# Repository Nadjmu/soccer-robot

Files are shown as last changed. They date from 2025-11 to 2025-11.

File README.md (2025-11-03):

# soccer-robot
This repository contains the schematic, the board design, the mechanical design (3D CAD Models) and the code for our autonomous soccer robot when we participated in the Soccer Lightweight League at the RoboCup Junior 2019. 

The rules can be found on the following website: https://junior.robocup.org/soccer/

The design of the motherboard and the ground board was done with Autodesk Eagle. The design of the mechanical components was done with the CAD Software Autodesk Inventor. The software was written with Arduino. 

This is a video where we played against Russia in the European Championship: https://www.youtube.com/watch?v=PZbQC_VygyU

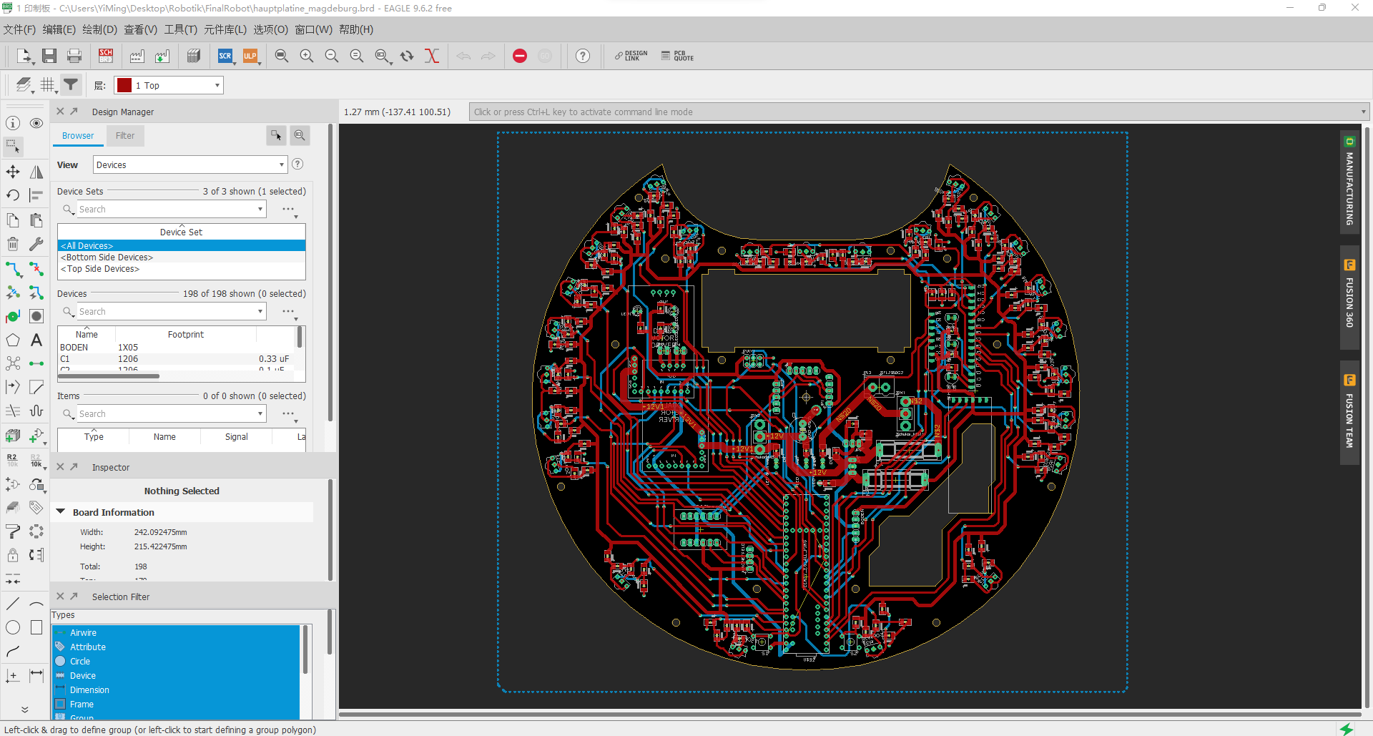
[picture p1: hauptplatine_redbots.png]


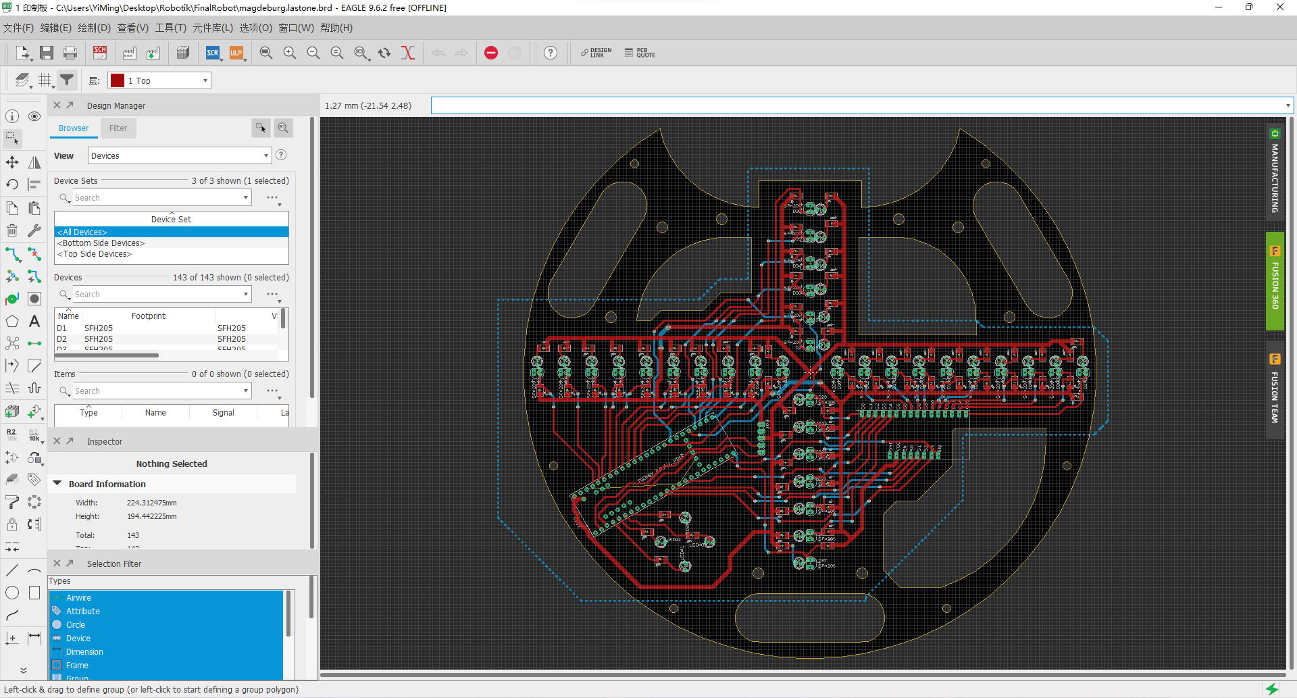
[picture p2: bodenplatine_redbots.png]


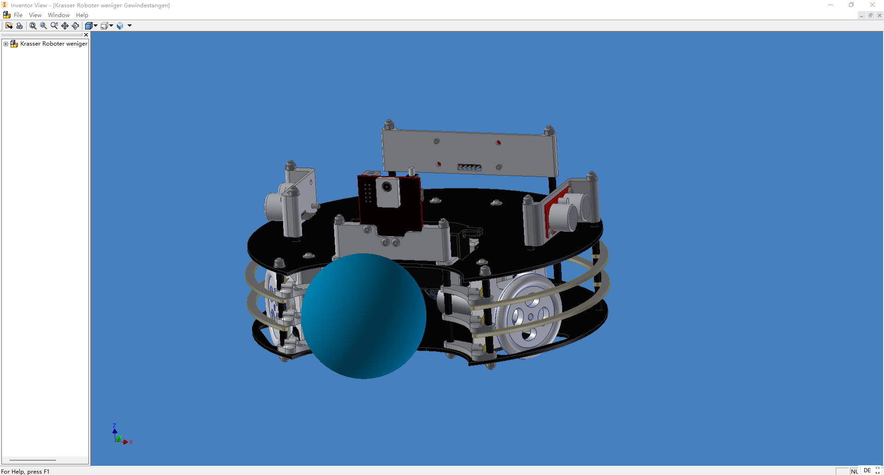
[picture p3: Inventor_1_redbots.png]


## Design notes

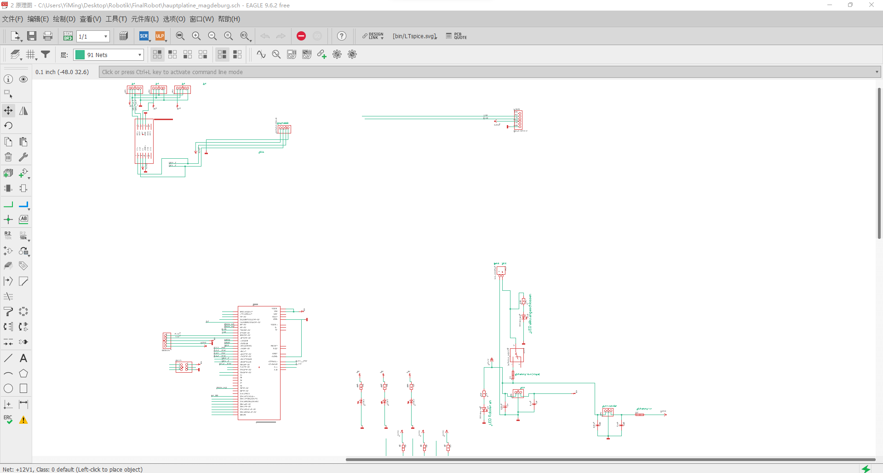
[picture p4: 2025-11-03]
schaltplan_redbots.png

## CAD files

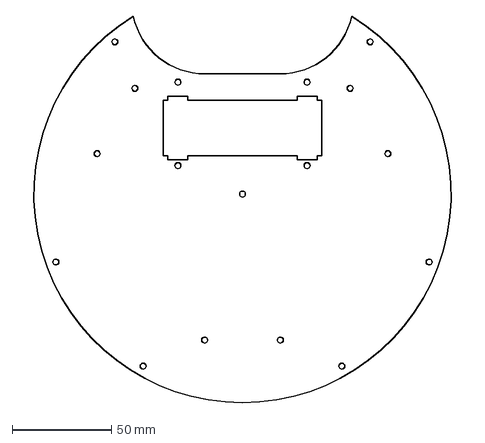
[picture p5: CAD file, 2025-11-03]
CAD_files/Hauptplatine.dxf
227.6 x 194.4 mm

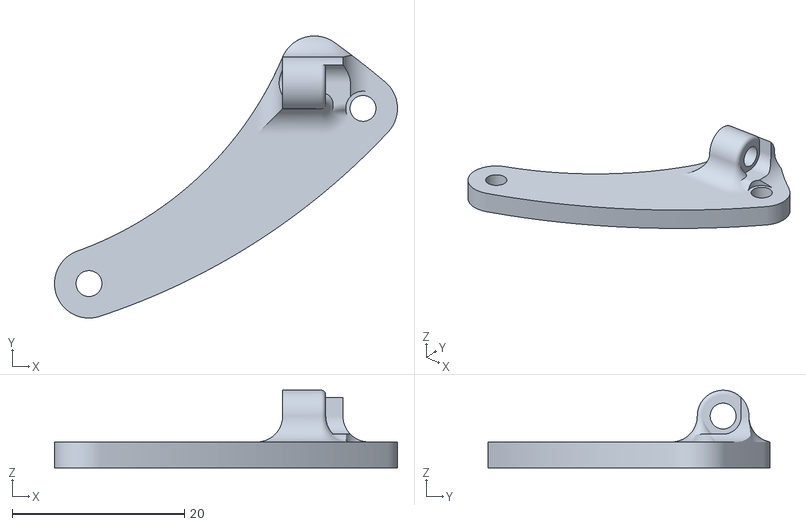
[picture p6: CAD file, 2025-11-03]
CAD_files/STL/Halterung Lichtschranke links.stl
39.8 x 32.7 x 9.00

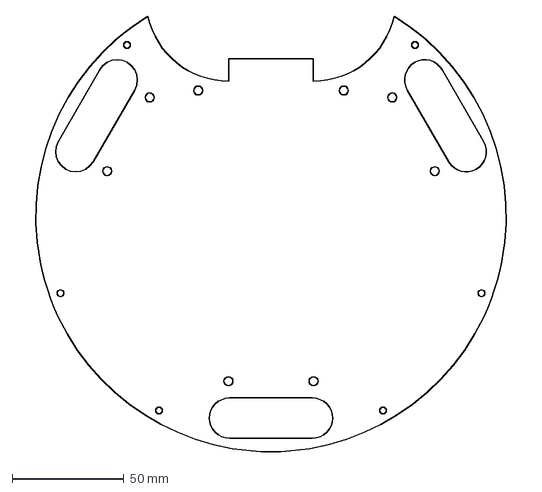
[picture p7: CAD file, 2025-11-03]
CAD_files/umriss.dxf
227.6 x 194.4 mm

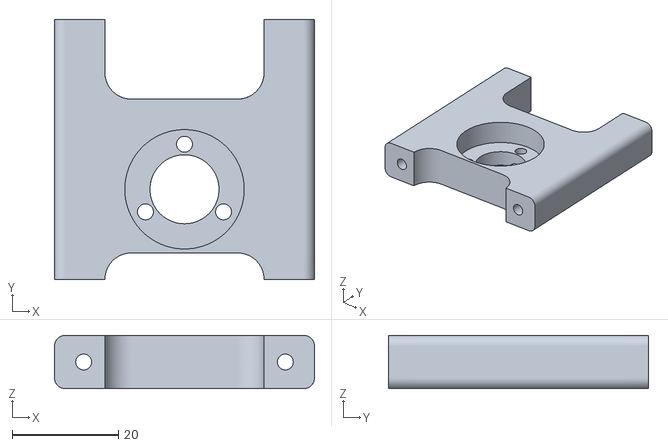
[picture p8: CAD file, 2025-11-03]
CAD_files/STL/Motorhalterung leicht versuch dünn.stl
49.0 x 49.0 x 10.0

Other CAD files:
CAD_files/STL/Halterung Lichtschranke rechts 2,9.stl
CAD_files/STL/Halterung Lichtschranke rechts.stl
CAD_files/STL/Halterung Lichtschranke rechts 2,8.stl
CAD_files/STL/Halterung Lichtschranke links 2,9.stl
CAD_files/STL/Halterung Lichtschranke links 2,8.stl
CAD_files/Abstandshalter 12mm leicht.ipt
CAD_files/Abstandshalter 12mm.ipt
CAD_files/Abstandshalter 14mm leicht.ipt
CAD_files/Abstandshalter 15mm leicht.ipt
CAD_files/Abstandshalter 15mm.ipt
CAD_files/Abstandshalter 3mm.ipt
CAD_files/Abstandshalter US Sensor.ipt
CAD_files/Akku.ipt
CAD_files/Akkuhalterung.ipt
CAD_files/Ball.ipt
CAD_files/Bodenplatine.ipt
CAD_files/DS1013-10SSiB.ipt
CAD_files/DS1022-1x3RD61.ipt
CAD_files/Fake Motor.ipt
CAD_files/Fake Rad.ipt
CAD_files/Gewindestange M3x100mm.ipt
CAD_files/Gewindestange M3x103mm.ipt
CAD_files/Gewindestange M3x63mm.ipt
CAD_files/Gewindestange M3x70mm.ipt
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

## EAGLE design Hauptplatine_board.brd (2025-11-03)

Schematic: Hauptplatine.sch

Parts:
BODEN: PINHD-1X5; 1X05
C1: 0.33 uF; 1206
C2: 0.1 uF; 1206
C3: RAD 470/25; E5-10,5
C4, C6, C8, C10, C12, C14, C15, C18, C19, C22, C23, C27, C29, C31, C35, C37, C39, C43, C47, C49, C51, C53, C55, C79, C81: 1u; 1206
C5, C7, C9, C11, C13, C16, C17, C20, C21, C24, C26, C28, C30, C32, C36, C38, C40, C44, C48, C50, C52, C54, C56, C80, C82: 100n; 1206
C59: 0,33 uF; 1206
C60: 0,1uF; 1206
D1, D4: LED 6mm weiß; L3R2-08
D2, D3, D5: SFH205
D16: LED 6mm gruen; L3R2-08
F1, F2: SH22,5
IR1, IR2, IR3, IR4, IR5, IR6, IR7, IR8, IR9, IR10, IR11, IR12, IR13, IR14, IR15, IR16, IR17, IR18, IR19, IR20, IR21, IR23, IR24, IR25, IR26: TSOP4038; TSOP581X
JP1, JP2, JP3: PINHD-1X5; 1X05
JP4, JP7: PINHD-1X2; 1X02
JP5, JP6: PINHD-1X3; 1X03
LED1, LED2, LED3: LED3MM
MAGNETFELD: PINHD-1X4; 1X04
PIXY1: PINHD-2X3; 2X03
PL3: STLZ950G2; S940_2
R1, R20, R22, R24, R26, R28, R30, R32, R35, R41, R47, R50, R53, R56, R59, R62, R65, R68, R71, R74, R77, R79, R80, R85, R86, R87, R93, R95, R141, R144: 4.7k; 1206
R2, R3, R4: 60R; 1206
R5, R6, R7: 5k; 1206
R19, R21, R23, R25, R27, R29, R31, R34, R40, R46, R49, R52, R55, R58, R61, R64, R67, R70, R73, R76, R84, R92, R94, R140, R143: 100k; 1206
R33, R36, R37, R38, R39, R42, R43, R44, R45, R48, R51, R54, R57, R60, R63, R66, R69, R72, R75, R78, R124, R127, R128, R142, R145: 10R; 1206
S1, S2: KSM611A
SW1, SW2: Schukat_MS111; MSS13ASP
U$1, U$6: MOTOR_DRIVER_MODULE
U$28: BLUETOTHA
U$32: TEENSY_3.6_ALL_PINS
U$58: LOGICLEVEL
X1: ANALOG/DIGITAL-MUX-BREAKOUT

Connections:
3.3V: U$32.3.3V, U$32.3.3V3 (3.3V), U$32.3.3V4 (3.3V)
+3V3: BODEN.1, F2.2, MAGNETFELD.1, R5.1, R6.1, R7.1, R20.2, R22.2, R24.2, R26.2, R28.2, R30.2, R32.2, R33.2, R35.2, R36.2, R37.2, R38.2, R39.2, R41.2, R42.2, R43.2, R44.2, R45.2, R47.2, R48.2, R50.2, R51.2, R53.2, R54.2, R56.2, R57.2, R59.2, R60.2, R62.2, R63.2, R65.2, R66.2, R68.2, R69.2, R71.2, R72.2, R74.2, R75.2, R77.2, R78.2, R79.2, R80.2, R87.2, R93.2, R95.2, R124.2, R127.2, R128.2, R141.2, R142.2, R144.2, R145.2, U$28.VCC, U$58.9 (LV), X1.VCC
+5V: BODEN.3, C2.2, JP1.1, JP2.1, JP3.1, JP6.3, PIXY1.2, R2.1, R3.1, R4.1, U$1.+5V, U$6.+5V, U$32.VIN, U$32.VUSB, U$58.3 (HV)
+12V: C1.2, C3.+, C59.2, F1.1, JP5.1, JP6.1, R86.2, SW2.U (U1)
+12V1: R1.2, SW2.2 (R1), U$1.VCC@1 (VCC), U$1.VCC@2 (VCC), U$1.VCC@3 (VCC), U$6.VCC@1 (VCC), U$6.VCC@2 (VCC), U$6.VCC@3 (VCC)
AA_00: U$32.32/A13 (32/A13/TX4/SCK1), X1.SIG (COM)
AREF: U$32.AREF
A_01: C4.1, R19.2, X1.P$16 (16)
A_02: C6.1, R21.2, X1.P$15 (15)
A_03: C8.1, R23.2, X1.P$14 (14)
A_04: C10.1, R25.2, X1.P$13 (13)
A_05: C14.1, R49.2, X1.P$12 (12)
A_06: C12.1, R27.2, X1.P$11 (11)
A_07: C18.1, R55.2, X1.P$10 (10)
A_08: C15.1, R29.2, X1.P$9 (9)
A_09: C19.1, R31.2, X1.P$7 (7)
A_10: C23.1, R34.2, X1.P$8 (8)
A_11: C27.1, R40.2, U$32.23/A9 (23/A9/T/PWM)
A_12: C31.1, R46.2, U$32.39/A20
A_13: C35.1, R52.2, U$32.A21 (A21/DAC0)
A_14: C39.1, R58.2, U$32.21/A7 (21/A7/PWM)
A_15: C22.1, R61.2, U$32.22/A8 (22/A8/T/PWM)
A_16: C43.1, R64.2, U$32.34/A15 (34/A15/RX5/CAN1-RX)
A_17: C29.1, R67.2, U$32.35/A16 (35/A16/PWM)
A_18: C47.1, R70.2, U$32.36/A17 (36/A17/PWM)
A_19: C49.1, R73.2, U$32.37/A18 (37/A18/SCL1/PWM)
A_20: C51.1, R76.2, U$32.38/A19 (38/A19/SDA1/PWM)
A_21: C37.1, R84.2, U$32.33/A14 (33/A14/TX5/CAN1-TX)
A_24: C53.1, R92.2, X1.P$4 (4)
A_25: C79.1, R140.2, U$32.A11
A_26: C55.1, R94.2, X1.P$5 (5)
A_27: C81.1, R143.2, X1.P$6 (6)
D1.1__FW: U$1.M1_FW_SIG (IN1_FW), U$32.14/A0 (14/A0/PWM)
D1.2__RW: U$1.M1_RW_SIG (IN1_RW), U$32.20/A6 (20/A6/PWM)
D2.1__FW: U$1.M2_FW_SIG (IN2_FW), U$32.A22 (A22/DAC1)
D2.2__RW: U$1.M2_RW_SIG (IN2_RW), U$32.15/A1 (15/A1/T)
D3.1__FW: U$6.M1_FW_SIG (IN1_FW), U$32.16/A2 (16/A2/T/PWM)
D3.2__RW: U$6.M1_RW_SIG (IN1_RW), U$32.17/A3 (17/A3/T/PWM)
GND: BODEN.2, C1.1, C2.1, C3.-, C4.2, C5.2, C6.2, C7.2, C8.2, C9.2, C10.2, C11.2, C12.2, C13.2, C14.2, C15.2, C16.2, C17.2, C18.2, C19.2, C20.2, C21.2, C22.2, C23.2, C24.2, C26.2, C27.2, C28.2, C29.2, C30.2, C31.2, C32.2, C35.2, C36.2, C37.2, C38.2, C39.2, C40.2, C43.2, C44.2, C47.2, C48.2, C49.2, C50.2, C51.2, C52.2, C53.2, C54.2, C55.2, C56.2, C59.1, C60.1, C79.2, C80.2, C81.2, C82.2, D1.2 (K), D2.A, D3.A, D4.2 (K), D5.A, D16.2 (K), IR1.2 (GND), IR2.2 (GND), IR3.2 (GND), IR4.2 (GND), IR5.2 (GND), IR6.2 (GND), IR7.2 (GND), IR8.2 (GND), IR9.2 (GND), IR10.2 (GND), IR11.2 (GND), IR12.2 (GND), IR13.2 (GND), IR14.2 (GND), IR15.2 (GND), IR16.2 (GND), IR17.2 (GND), IR18.2 (GND), IR19.2 (GND), IR20.2 (GND), IR21.2 (GND), IR23.2 (GND), IR24.2 (GND), IR25.2 (GND), IR26.2 (GND), JP1.5, JP2.5, JP3.5, JP5.2, JP6.2, LED1.K (C), LED2.K (C), LED3.K (C), MAGNETFELD.4, PIXY1.6, PL3.2, S1.A, S1.C, S2.A, S2.C, U$1.GND@1 (GND), U$1.GND@2 (GND), U$1.GND@3 (GND), U$1.GND@4 (GND), U$6.GND@1 (GND), U$6.GND@2 (GND), U$6.GND@3 (GND), U$6.GND@4 (GND), U$28.GND, U$32.AGND, U$32.GND, U$32.GND1 (GND), U$32.GND3 (GND), U$32.GND4 (GND), U$32.GND6 (GND), U$58.4 (GND), U$58.10 (GND1), X1.GND
K1: R79.1, S1.B, S1.D, U$32.24
K2: R80.1, S2.B, S2.D, U$32.4 (4/CAN0-RX/SDA2/PWM)
LI1: D5.K (C), R6.2, X1.P$1 (1)
LI2: D3.K (C), R5.2, X1.P$2 (2)
LI3: D2.K (C), R7.2, X1.P$3 (3)
MISO: PIXY1.1, U$32.12 (12/MISO0)
MOSI: PIXY1.4, U$32.11 (11/MOSI0)
unnamed: JP4.2, U$6.M1_FW (OUT1_FW)
unnamed: F1.2, SW1.1 (A1)
unnamed: JP4.1, U$6.M1_RW (OUT1_RW)
unnamed: C60.2, F2.1, JP5.3
unnamed: JP7.2, U$6.M2_FW (OUT2_FW)
unnamed: JP7.1, U$6.M2_RW (OUT2_RW)
unnamed: LED3.A, R2.2
unnamed: LED1.A, R3.2
unnamed: LED2.A, R4.2
unnamed: D4.1 (A), R1.1
unnamed: PL3.1, R85.2, SW1.U (U1)
unnamed: IR1.1 (VO), R19.1, R20.1
unnamed: C5.1, IR1.3 (VS), R33.1
unnamed: IR2.1 (VO), R21.1, R22.1
unnamed: C7.1, IR2.3 (VS), R36.1
unnamed: IR3.1 (VO), R23.1, R24.1
unnamed: C9.1, IR3.3 (VS), R37.1
unnamed: IR4.1 (VO), R25.1, R26.1
unnamed: C11.1, IR4.3 (VS), R38.1
unnamed: IR6.1 (VO), R27.1, R28.1
unnamed: C13.1, IR6.3 (VS), R39.1
unnamed: IR8.1 (VO), R29.1, R30.1
unnamed: IR9.1 (VO), R31.1, R32.1
unnamed: C20.1, IR9.3 (VS), R43.1
unnamed: IR10.1 (VO), R34.1, R35.1
unnamed: C24.1, IR10.3 (VS), R44.1
unnamed: C16.1, IR8.3 (VS), R42.1
unnamed: IR5.1 (VO), R49.1, R50.1
unnamed: IR11.1 (VO), R40.1, R41.1
unnamed: C28.1, IR11.3 (VS), R45.1
unnamed: IR12.1 (VO), R46.1, R47.1
unnamed: C32.1, IR12.3 (VS), R48.1
unnamed: C17.1, IR5.3 (VS), R51.1
unnamed: IR7.1 (VO), R55.1, R56.1
unnamed: C21.1, IR7.3 (VS), R57.1
unnamed: IR15.1 (VO), R61.1, R62.1
unnamed: C26.1, IR15.3 (VS), R63.1
unnamed: IR17.1 (VO), R67.1, R68.1
unnamed: C30.1, IR17.3 (VS), R69.1
unnamed: IR21.1 (VO), R84.1, R87.1
unnamed: C38.1, IR21.3 (VS), R124.1
unnamed: IR13.1 (VO), R52.1, R53.1
unnamed: C36.1, IR13.3 (VS), R54.1
unnamed: IR14.1 (VO), R58.1, R59.1
unnamed: C40.1, IR14.3 (VS), R60.1
unnamed: IR23.1 (VO), R92.1, R93.1
unnamed: C54.1, IR23.3 (VS), R127.1
unnamed: IR25.1 (VO), R94.1, R95.1
unnamed: C56.1, IR25.3 (VS), R128.1
unnamed: IR16.1 (VO), R64.1, R65.1
unnamed: C44.1, IR16.3 (VS), R66.1
unnamed: IR18.1 (VO), R70.1, R71.1
unnamed: C48.1, IR18.3 (VS), R72.1
unnamed: IR19.1 (VO), R73.1, R74.1
unnamed: C50.1, IR19.3 (VS), R75.1
unnamed: IR20.1 (VO), R76.1, R77.1
unnamed: C52.1, IR20.3 (VS), R78.1
unnamed: IR24.1 (VO), R140.1, R141.1
unnamed: C80.1, IR24.3 (VS), R142.1
unnamed: IR26.1 (VO), R143.1, R144.1
unnamed: C82.1, IR26.3 (VS), R145.1
unnamed: D16.1 (A), R85.1
unnamed: D1.1 (A), R86.1
PWM_M1: U$1.M1_PWM_SIG (IN1_PWM), U$32.5 (5/PWM)
PWM_M2: U$1.M2_PWM_SIG (IN2_PWM), U$32.6 (6/PWM)
PWM_M3: U$6.M1_PWM_SIG (IN1_PWM), U$32.29 (29/T/PWM)
RX2: BODEN.5, U$32.9 (9/RX2/PWM)
RXB: U$28.TX, U$32.7 (7/RX3/PWM)
SCK: PIXY1.3, U$32.13 (13/SCK0/LED)
SCL_2: MAGNETFELD.2, U$32.19/A5 (19/A5/T/SCL0), U$58.8 (LV2)
SCL_ULT: JP1.3, JP2.3, JP3.3, U$58.2 (HV2)
SDA_2: MAGNETFELD.3, U$32.18/A4 (18/A4/T/SDA0), U$58.7 (LV1)
SDA_ULT: JP1.2, JP2.2, JP3.2, U$58.1 (HV1)
S_0: U$32.0 (0/RX1/MOSI1/T), X1.S0
S_1: U$32.1 (1/TX1/MISO1/T), X1.S1
S_2: U$32.2 (2/PWM), X1.S2
S_3: U$32.3 (3/CAN0-TX/SCL2/PWM), X1.S3
TX2: BODEN.4, U$32.10 (10/TX2/PWM)
TXB: U$28.RX, U$32.8 (8/TX3/PWM)
VBAT: U$32.VBAT
VUSB1: U$32.VUSB1

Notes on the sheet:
Akku
VCC
GND
LED akku angeschlossen
LED Roboter an
+5V
Torwrt
feldspieler
magnetfeld
sicherung 16 A (Träge)
sicherung 1 A
echter NAME TSSP4038
0.1uF und 100nF ist Dasselbe!!!!!!!!!!!!!!!!!!!!!!!!!!!!!!!!!!!!!!!!!!!!!!!!!!!!!!!!!!!!!!!!!!!!!!!!
3,3 V wandler
LED Motoren an

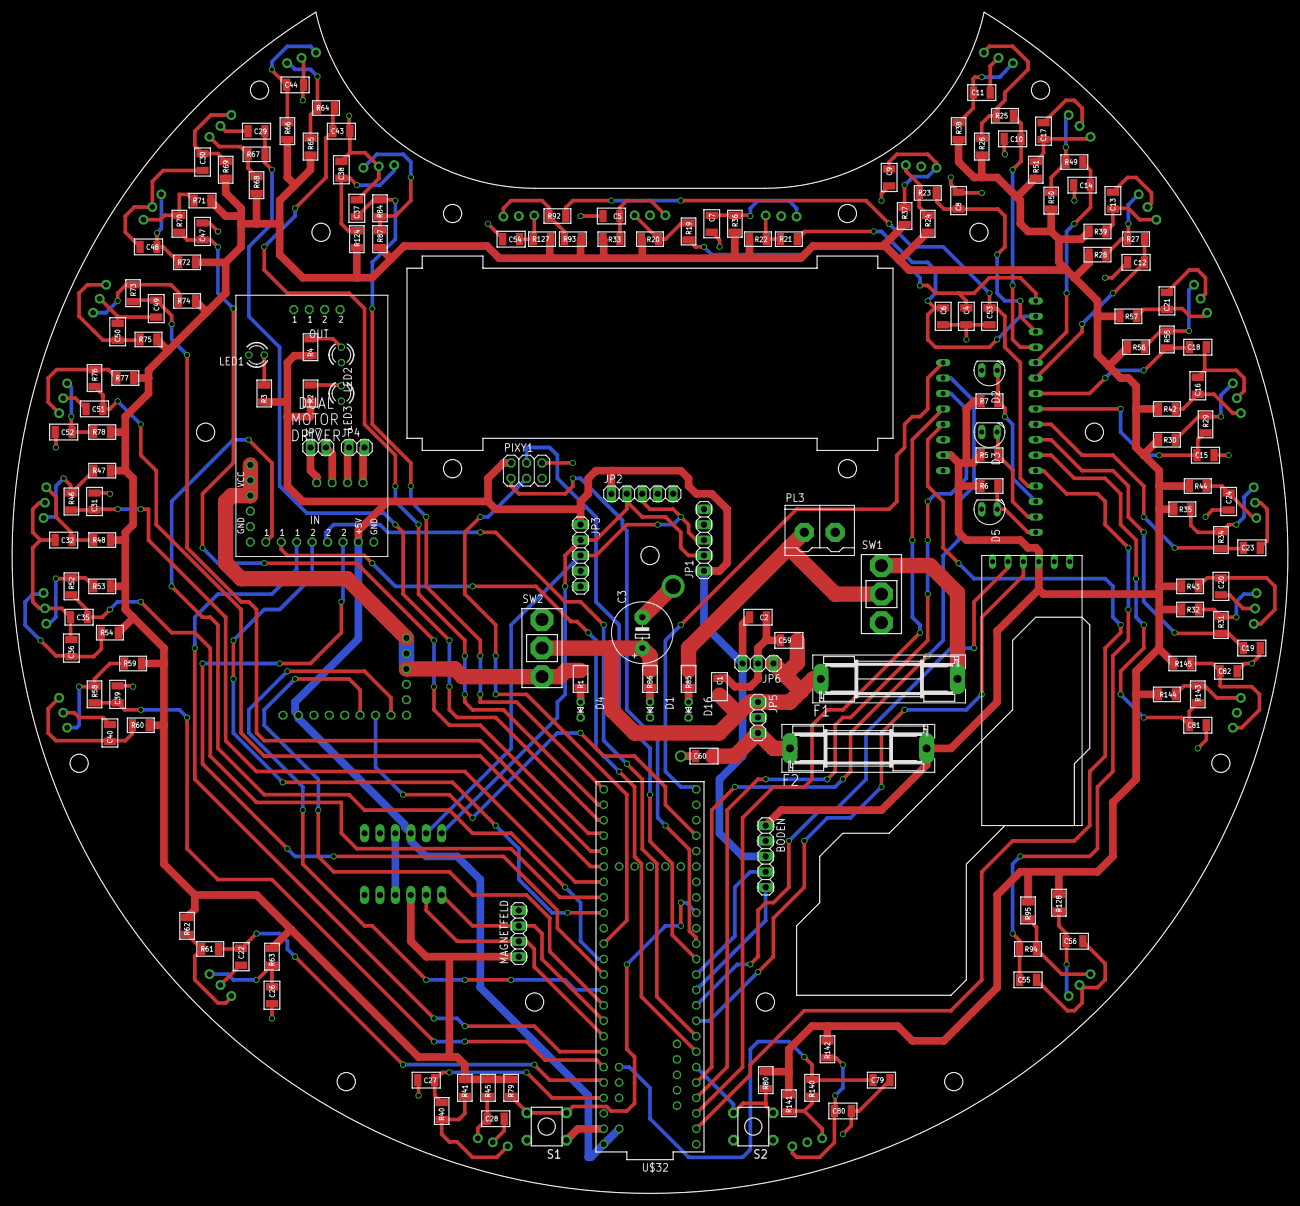
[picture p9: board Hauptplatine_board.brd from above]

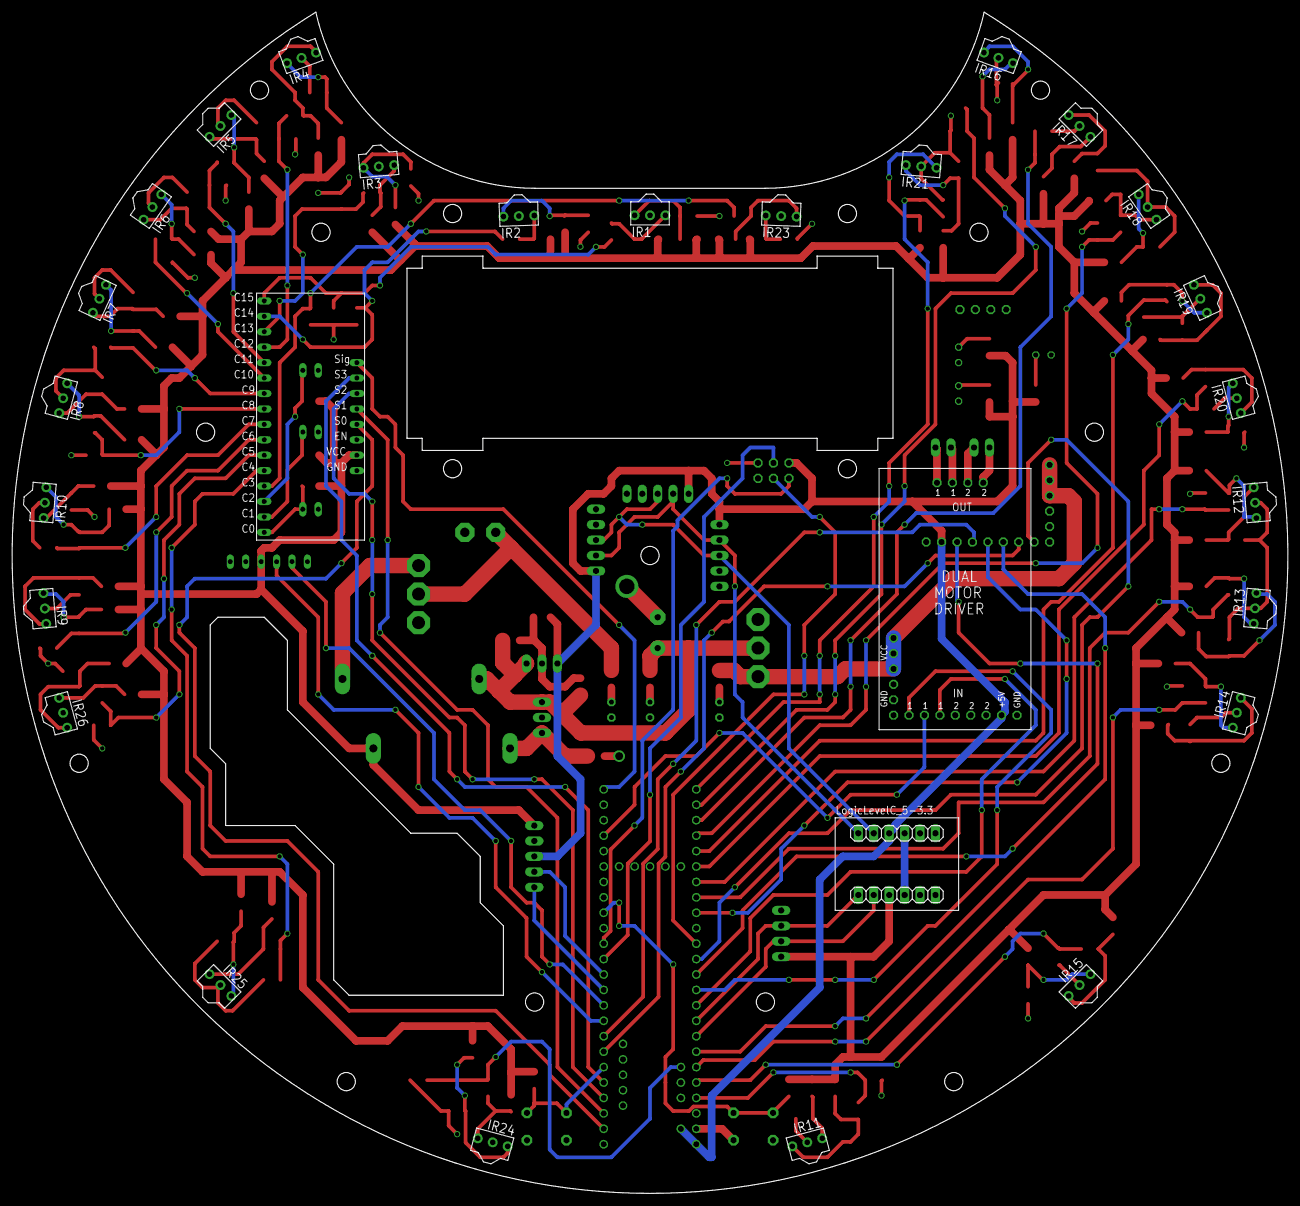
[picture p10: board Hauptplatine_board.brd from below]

Board: 2 copper layers, 210.0 x 194.4 mm, 198 parts (28 on the bottom side), 124 nets.

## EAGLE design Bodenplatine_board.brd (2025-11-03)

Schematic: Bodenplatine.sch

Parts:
D1, D2, D3, D4, D5, D6, D7, D8, D9, D10, D11, D13, D14, D15, D16, D17, D18, D19, D20, D21, D22, D23, D24, D25, D26, D27, D28, D29, D30, D34, D35, D36, D37: SFH205
JP1: PINHD-1X5; 1X05
LED1, LED2, LED3, LED4, LED5, LED6, LED7, LED8, LED9, LED10, LED11, LED12, LED14, LED15, LED16, LED17, LED18, LED19, LED20, LED21, LED22, LED23, LED24, LED25, LED26, LED27, LED28, LED29, LED30, LED31, LED32, LED33, LED34, LED38, LED40, LED41, LED42: LED3MM
R1, R2, R4, R5, R8, R10, R14, R15, R17, R19, R21, R23, R26, R28, R29, R30, R32, R34, R38, R40, R41, R42, R43, R45, R47, R48, R49, R50, R52, R54, R55, R56, R58, R59, R61, R62, R68: 60R; 1206
R3, R6, R7, R9, R11, R12, R13, R16, R18, R20, R22, R24, R25, R27, R31, R33, R35, R36, R39, R44, R46, R51, R53, R64, R65, R66, R67, R71, R72, R73, R78, R79, R80: 5k; 1206
U$32: TEENSY_3.6_ALL_PINS
X1: ANALOG/DIGITAL-MUX-BREAKOUT

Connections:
3.3V: U$32.3.3V, U$32.3.3V3 (3.3V), U$32.3.3V4 (3.3V)
+3V3: JP1.1, R3.1, R6.1, R7.1, R9.1, R11.1, R12.1, R13.1, R16.1, R18.1, R20.1, R22.1, R24.1, R25.1, R27.1, R31.1, R33.1, R35.1, R36.1, R39.1, R44.1, R46.1, R51.1, R53.1, R64.1, R65.1, R66.1, R67.1, R71.1, R72.1, R73.1, R78.1, R79.1, R80.1, X1.VCC
+5V: JP1.3, R1.1, R2.1, R4.1, R5.1, R8.1, R10.1, R14.1, R15.1, R17.1, R19.1, R21.1, R23.1, R26.1, R28.1, R29.1, R30.1, R32.2, R34.1, R38.1, R40.2, R41.1, R42.2, R43.2, R45.1, R47.1, R48.1, R49.1, R50.1, R52.1, R54.1, R55.1, R56.1, R58.1, U$32.VIN, U$32.VUSB
A1: D16.K (C), R7.2, U$32.15/A1 (15/A1/T)
A2: D15.K (C), R9.2, U$32.16/A2 (16/A2/T/PWM)
A3: D14.K (C), R11.2, U$32.17/A3 (17/A3/T/PWM)
A4: D13.K (C), R13.2, U$32.18/A4 (18/A4/T/SDA0)
A5: D9.K (C), R18.2, U$32.19/A5 (19/A5/T/SCL0)
A6: D8.K (C), R20.2, U$32.20/A6 (20/A6/PWM)
A7: D7.K (C), R22.2, U$32.21/A7 (21/A7/PWM)
A8: D6.K (C), R25.2, U$32.22/A8 (22/A8/T/PWM)
A9: D5.K (C), R27.2, U$32.23/A9 (23/A9/T/PWM)
A10: D2.K (C), R33.2, U$32.A21 (A21/DAC0)
A11: D1.K (C), R35.2, U$32.A22 (A22/DAC1)
A13: D37.K (C), R64.2, U$32.32/A13 (32/A13/TX4/SCK1)
A14: D36.K (C), R65.2, U$32.33/A14 (33/A14/TX5/CAN1-TX)
A15: D35.K (C), R66.2, U$32.34/A15 (34/A15/RX5/CAN1-RX)
A16: D34.K (C), R67.2, U$32.35/A16 (35/A16/PWM)
A17: D30.K (C), R71.2, U$32.36/A17 (36/A17/PWM)
A18: D29.K (C), R72.2, U$32.37/A18 (37/A18/SCL1/PWM)
A19: D28.K (C), R73.2, X1.P$1 (1)
A20: D23.K (C), R78.2, X1.P$2 (2)
A21: D22.K (C), R79.2, X1.P$3 (3)
A22: D21.K (C), R80.2, X1.P$4 (4)
A23: D3.K (C), R3.2, X1.P$5 (5)
A24: D4.K (C), R6.2, X1.P$6 (6)
A25: D10.K (C), R12.2, X1.P$7 (7)
A26: D11.K (C), R16.2, X1.P$8 (8)
A27: D17.K (C), R24.2, X1.P$9 (9)
A28: D18.K (C), R31.2, X1.P$10 (10)
A29: D19.K (C), R36.2, X1.P$11 (11)
A30: D20.K (C), R39.2, X1.P$12 (12)
A31: D24.K (C), R44.2, X1.P$13 (13)
A32: D25.K (C), R46.2, X1.P$14 (14)
A33: D26.K (C), R51.2, X1.P$15 (15)
A34: D27.K (C), R53.2, X1.P$16 (16)
AREF: U$32.AREF
GND: D1.A, D2.A, D3.A, D4.A, D5.A, D6.A, D7.A, D8.A, D9.A, D10.A, D11.A, D13.A, D14.A, D15.A, D16.A, D17.A, D18.A, D19.A, D20.A, D21.A, D22.A, D23.A, D24.A, D25.A, D26.A, D27.A, D28.A, D29.A, D30.A, D34.A, D35.A, D36.A, D37.A, JP1.2, LED1.K (C), LED2.K (C), LED3.K (C), LED4.K (C), LED5.K (C), LED6.K (C), LED7.K (C), LED8.K (C), LED9.K (C), LED10.K (C), LED11.K (C), LED12.K (C), LED14.K (C), LED15.K (C), LED16.K (C), LED17.K (C), LED18.K (C), LED19.K (C), LED20.K (C), LED21.K (C), LED22.K (C), LED23.K (C), LED24.K (C), LED25.K (C), LED26.K (C), LED27.K (C), LED28.K (C), LED29.K (C), LED30.K (C), LED31.K (C), LED32.K (C), LED33.K (C), LED34.K (C), LED38.K (C), LED40.K (C), LED41.K (C), LED42.K (C), U$32.AGND, U$32.GND, U$32.GND1 (GND), U$32.GND3 (GND), U$32.GND4 (GND), U$32.GND6 (GND), X1.GND
unnamed: LED8.A, R1.2
unnamed: LED11.A, R2.2
unnamed: LED23.A, R5.2
unnamed: LED10.A, R4.2
unnamed: LED24.A, R8.2
unnamed: LED25.A, R15.2
unnamed: LED26.A, R21.2
unnamed: LED27.A, R29.2
unnamed: LED28.A, R34.2
unnamed: LED9.A, R10.2
unnamed: LED29.A, R38.2
unnamed: LED30.A, R40.1
unnamed: LED12.A, R23.2
unnamed: LED31.A, R45.2
unnamed: LED32.A, R47.2
unnamed: LED7.A, R14.2
unnamed: LED33.A, R52.2
unnamed: LED6.A, R17.2
unnamed: LED3.A, R32.1
unnamed: LED5.A, R19.2
unnamed: LED34.A, R58.2
unnamed: LED41.A, R59.2
unnamed: LED42.A, R61.2
unnamed: LED40.A, R62.2
unnamed: LED38.A, R68.2
unnamed: LED4.A, R26.2
unnamed: LED2.A, R28.2
unnamed: LED1.A, R30.2
unnamed: R68.1, U$32.5 (5/PWM)
unnamed: LED22.A, R41.2
unnamed: LED21.A, R42.1
unnamed: LED20.A, R43.1
unnamed: LED19.A, R48.2
unnamed: LED18.A, R49.2
unnamed: LED17.A, R50.2
unnamed: LED16.A, R54.2
unnamed: LED15.A, R55.2
unnamed: LED14.A, R56.2
RIX2: R62.1, U$32.4 (4/CAN0-RX/SDA2/PWM)
RIX3: R61.1, U$32.3 (3/CAN0-TX/SCL2/PWM)
RIX4: R59.1, U$32.2 (2/PWM)
RX: JP1.5, U$32.1 (1/TX1/MISO1/T)
SIG: U$32.31/A12 (31/A12/RX4), X1.SIG (COM)
S_0: U$32.24, X1.S0
S_1: U$32.12 (12/MISO0), X1.S1
S_2: U$32.11 (11/MOSI0), X1.S2
S_3: U$32.10 (10/TX2/PWM), X1.S3
TX: JP1.4, U$32.0 (0/RX1/MOSI1/T)
VBAT: U$32.VBAT
VUSB1: U$32.VUSB1

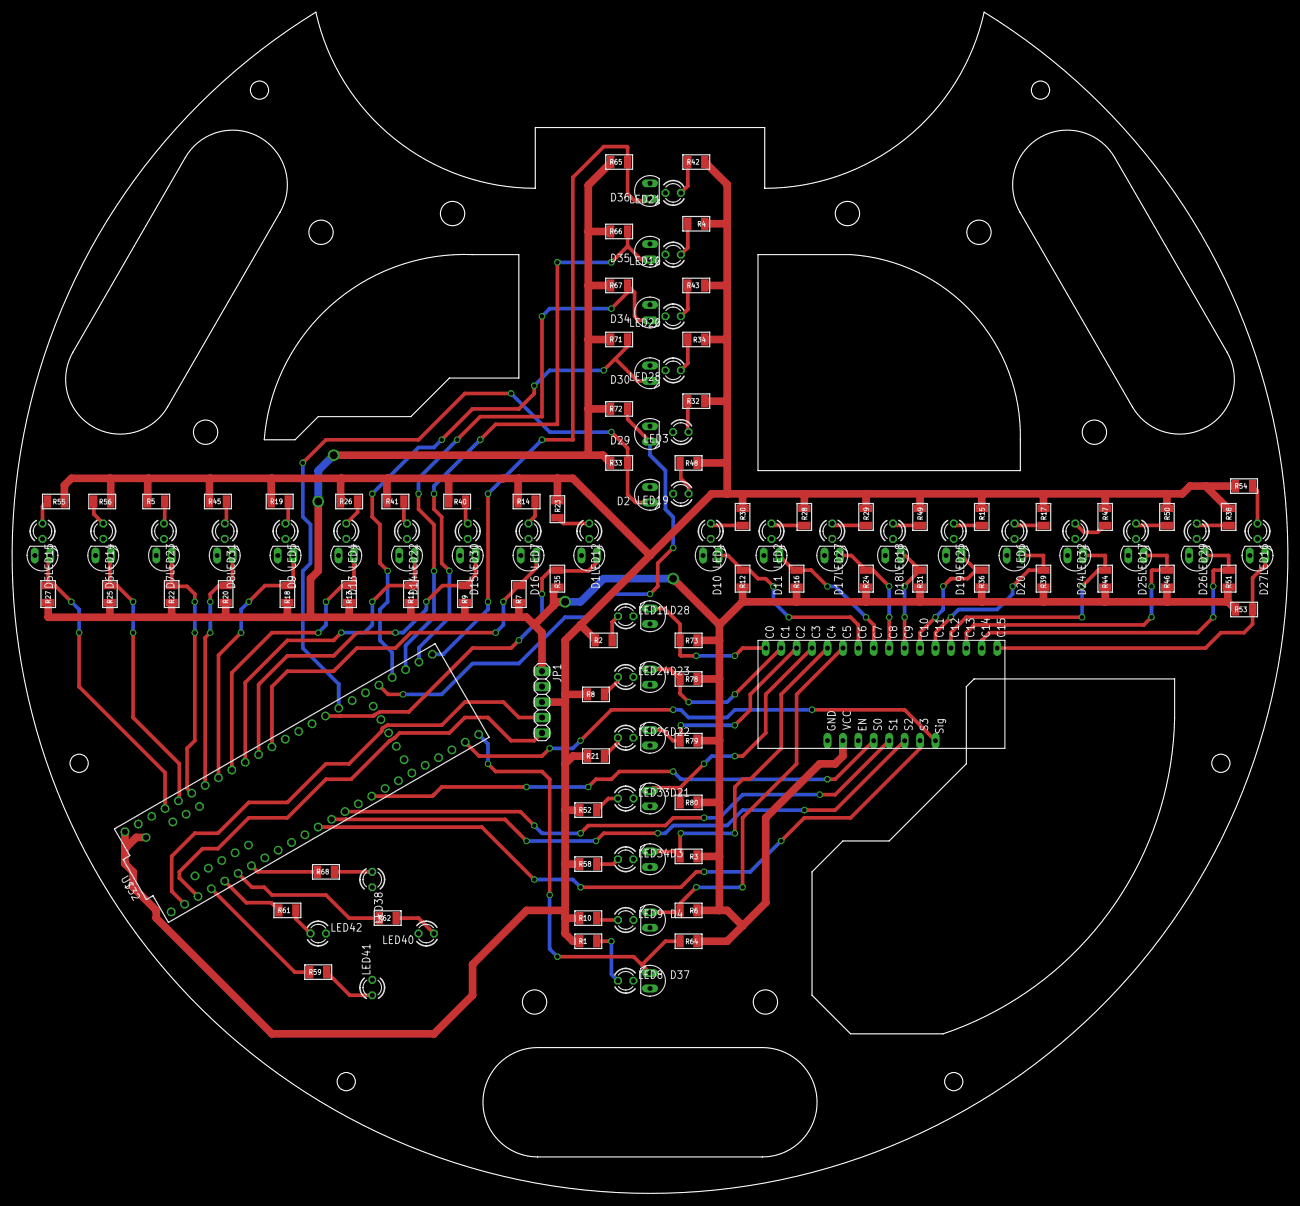
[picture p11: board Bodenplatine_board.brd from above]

Board: 2 copper layers, 210.0 x 194.4 mm, 143 parts (0 on the bottom side), 85 nets.

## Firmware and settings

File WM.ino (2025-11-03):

#include <EEPROM.h>
#include <i2c_t3.h>

#include <SPI.h>
#include <Pixy.h>
#include <Teensy_LSM9DS1.h>

Pixy pixy;
uint16_t blocks;

LSM9DS1 imu;

#define LSM9DS1_M  0x1E // Would be 0x1C if SDO_M is LOW
#define LSM9DS1_AG  0x6B // Would be 0x6A if SDO_AG is LOW

#define PRINT_CALCULATED
//#define PRINT_RAW
#define PRINT_SPEED 250 // 250 ms between prints

// Earth's magnetic field varies by location. Add or subtract
// a declination to get a more accurate heading. Calculate
// your's here:
// http://www.ngdc.noaa.gov/geomag-web/#declination
#define DECLINATION -8.58 // Di q1eclination (degrees) in Boulder, CO.


////////////////////VARIABLEN///////////////////////
bool torwart;
bool lichtschranke;
int mL, mR, mH, mSchuss;

int mRInA = 2;          //RECHTS
int mRInB = 37;
int mRPWM = 5;

int mHInA = 1;         //HINTEN
int mHInB = 39;
int mHPWM = 29;

int mLInA = 35;         //LINKS
int mLInB = 36;
int mLPWM = 30;

//    ULTRASCHALL
int us[4];
long aUS;
long bUS;
long cUS;
long dUS;
boolean usR;
boolean usL;
//    INFRAROT
int valueIR, bestIR;
float x;
float y;

int ir[36];
int ballAngle;
int distance;
int xSmooth;
int ySmooth;
int irspeed = 100;

double ballX;
double ballY;

double driveAngle;

int BallA;

bool BallRest;
//Boden
int z;

//

//    KOMPASS
int Abweichung;
int drehung;
int oldZeit;
int oldAbweichung;
//   Magnetfeld
int winkel;
int minx;
int miny;
int maxx;
int maxy;
int xmittel;
int ymittel;
int add1;
//
int r;
int p;

//PIXY
int pixyx;
int pixywidth;
int pixyheight;
int pixyAngle;
int pixyAbweichung = 60;

int j;
int d;
int w;

bool t;


void Lichtschranke() {
  lichtschranke = false;
  if (analogRead(A0) < 700) {
    lichtschranke = true;
  }
}

void Pixyy() {

  blocks = pixy.getBlocks();
  if (blocks) {
    pixyx = pixy.blocks[0].x - 160;
    pixywidth = pixy.blocks[0].width;
    pixyheight = pixy.blocks[0].height;
  }
}

////////////////////////////////////////////////////////////////////ULTRASCHALL///////////////////////////////////////////////////////////////////////////////////////
void US() {
  int reading0 = 0;
  int reading1 = 0;
  int reading2 = 0;
  int reading3 = 0;

  if (millis() > aUS + 10) {
    Wire2.beginTransmission(113);
    Wire2.write(byte(0x02));                    //Wert in Register schreiben
    Wire2.endTransmission();
    Wire2.requestFrom(113, 2);                  //Wert aufrufen und in 2 bytes schreiben
    if (2 <= Wire2.available()) {
      reading0 = Wire2.read();                   //größerer Byte
      reading0 = reading0 << 8;                  //8 bits
      reading0 |= Wire2.read();                  //niedrigerer Byte
      us[0] = reading0;
    }
    Wire2.beginTransmission(113);
    Wire2.write(byte(0x00));
    Wire2.write(byte(0x51));
    Wire2.endTransmission(113);
    aUS = millis();
  }

  if (millis() > bUS + 10) {
    Wire2.beginTransmission(114);
    Wire2.write(byte(0x02));                    //Wert in Register schreiben
    Wire2.endTransmission();
    Wire2.requestFrom(114, 2);                  //Wert aufrufen und in 2 bytes schreiben
    if (2 <= Wire2.available()) {
      reading1 = Wire2.read();                   //größerer Byte
      reading1 = reading1 << 8;                  //8 bits
      reading1 |= Wire2.read();                  //niedrigerer Byte
      us[1] = reading1;
    }
    Wire2.beginTransmission(114);
    Wire2.write(byte(0x00));
    Wire2.write(byte(0x51));
    Wire2.endTransmission(114);
    bUS = millis();
  }

  if (millis() > cUS + 10) {
    Wire2.beginTransmission(115);
    Wire2.write(byte(0x02));                    //Wert in Register schreiben
    Wire2.endTransmission();
    Wire2.requestFrom(115, 2);                  //Wert aufrufen und in 2 bytes schreiben
    if (2 <= Wire2.available()) {
      reading2 = Wire2.read();                   //größerer Byte
      reading2 = reading2 << 8;                  //8 bits
      reading2 |= Wire2.read();                  //niedrigerer Byte
      us[2] = reading2;
    }
    Wire2.beginTransmission(115);
    Wire2.write(byte(0x00));
    Wire2.write(byte(0x51));
    Wire2.endTransmission(115);
    cUS = millis();
  }

  if (millis() > dUS + 10) {
    Wire2.beginTransmission(116);
    Wire2.write(byte(0x02));                    //Wert in Register schreiben
    Wire2.endTransmission();
    Wire2.requestFrom(116, 2);                  //Wert aufrufen und in 2 bytes schreiben
    if (2 <= Wire2.available()) {
      reading3 = Wire2.read();                   //größerer Byte
      reading3 = reading3 << 8;                  //8 bits
      reading3 |= Wire2.read();                  //niedrigerer Byte
      us[3] = reading3;
    }
    Wire2.beginTransmission(116);
    Wire2.write(byte(0x00));
    Wire2.write(byte(0x51));
    Wire2.endTransmission(116);
    dUS = millis();
  }

}

void Torwart() {
  boolean mid = false;
  int dTor = 40;
  if (abs(us[0] - us[2]) < 40 && (us[0] + us[2]) > 100) {
    mid = true;
    x = 0;
  }
  if (!mid) {
    x = -50;
    if (us[2] < us[0]) {
      x = 50;
    }
  }
  if (us[3] > dTor) {
    y = -50;
  }
  else if (us[3] < dTor) {
    y = 0;
  }
}
////////////////////////////////////////////////////////////////////KOMPASS/////////////////////////////////////////////////////////////////////////////////////////////////
void MagDeg() {
  imu.readMag();
  xmittel = (maxx + minx) / 2;
  ymittel = (maxy + miny) / 2;
  winkel = atan2((imu.my - ymittel), (imu.mx - xmittel)) * 180. / M_PI;                                                       //KOMPASS TESTEN
}

void CompassRotate() {
  winkel = winkel - add1;
  if (winkel < -180) {
    winkel = 180 - (-winkel - 180);
  }
  if (winkel > 180) {
    winkel = -180 + (winkel - 180);
  }
  Abweichung = winkel;
  double p = 2.3;                    //p = 2.0
  double d = 1.2;                    //d = 1.1
  long zeit = millis() - oldZeit;

  int drehung = p * Abweichung + (d / zeit) * (Abweichung - oldAbweichung);
  oldAbweichung = Abweichung;
  oldZeit = zeit;
  r = drehung / 3;                                                                     //DREHUNG
}

//////////////////////////////////////////////////////////////////////////////////////////////////////77
void IR () {
  ir[0] = analogRead(A6);
  ir[1] = analogRead(A7);
  ir[2] = analogRead(A8);
  ir[3] = analogRead(A9);
  ir[4] = analogRead(A11);
  ir[5] = analogRead(A10);
  digitalWrite(31, HIGH); digitalWrite(32, HIGH); digitalWrite(33, HIGH); digitalWrite(34, HIGH); ir[6] = analogRead(15);   //C15
  digitalWrite(31, LOW); digitalWrite(32, HIGH); digitalWrite(33, HIGH); digitalWrite(34, HIGH); ir[7] = analogRead(15);    //C14
  digitalWrite(31, HIGH); digitalWrite(32, LOW); digitalWrite(33, HIGH); digitalWrite(34, HIGH); ir[8] = analogRead(15);    //C13
  digitalWrite(31, LOW); digitalWrite(32, LOW); digitalWrite(33, HIGH); digitalWrite(34, HIGH); ir[9] = analogRead(15);     //C12
  digitalWrite(31, HIGH); digitalWrite(32, HIGH); digitalWrite(33, LOW); digitalWrite(34, HIGH); ir[10] = analogRead(15);   //C11

  digitalWrite(31, LOW); digitalWrite(32, HIGH); digitalWrite(33, LOW); digitalWrite(34, HIGH); ir[11] = analogRead(15);   //C10
  digitalWrite(31, HIGH); digitalWrite(32, LOW); digitalWrite(33, LOW ); digitalWrite(34, HIGH); ir[12] = analogRead(15);       //C9
  digitalWrite(31, LOW); digitalWrite(32, LOW); digitalWrite(33, LOW); digitalWrite(34, HIGH); ir[13] = analogRead(15);     //C8
  digitalWrite(31, HIGH); digitalWrite(32, HIGH); digitalWrite(33, HIGH); digitalWrite(34, LOW); ir[14] = analogRead(15);     //C7
  digitalWrite(31, LOW); digitalWrite(32, HIGH); digitalWrite(33, HIGH); digitalWrite(34, LOW); ir[15] = analogRead(15);     //C6

  digitalWrite(31, HIGH); digitalWrite(32, LOW); digitalWrite(33, HIGH); digitalWrite(34, LOW); ir[16] = analogRead(15);     //C5
  digitalWrite(31, LOW); digitalWrite(32, LOW); digitalWrite(33, HIGH); digitalWrite(34, LOW); ir[17] = analogRead(15);     //C4
  digitalWrite(31, HIGH); digitalWrite(32, HIGH); digitalWrite(33, LOW); digitalWrite(34, LOW); ir[18] = analogRead(15);     //C3
  digitalWrite(31, LOW); digitalWrite(32, HIGH); digitalWrite(33, LOW); digitalWrite(34, LOW); ir[19] = analogRead(15);     //C2
  digitalWrite(31, HIGH); digitalWrite(32, LOW); digitalWrite(33, LOW); digitalWrite(34, LOW); ir[20] = analogRead(15);     //C1

  digitalWrite(31, LOW); digitalWrite(32, LOW); digitalWrite(33, LOW); digitalWrite(34, LOW); ir[21] = analogRead(15);      //C0

  ir[22] = 10000;
  ir[23] = 10000;

  ir[24] = analogRead(A21);

  ir[25] = 10000;
  ir[26] = 10000;

  ir[27] = analogRead(A22);

  ir[28] = 10000;
  ir[29] = 10000;

  ir[30] = analogRead(A2);

  ir[31] = 10000;
  ir[32] = 10000;

  ir[33] = analogRead(A3);
  ir[34] = analogRead(A4);
  ir[35] = analogRead(A5);

}

void IRAlgorithm() {
  pixyAngle = 0;
  valueIR = 1023;
  bestIR = 36;
  BallA = 100;
  int v = 1;
  for (int i = 0; i < 36; i++) {
    if (ir[i] < valueIR) {
      bestIR = i;
      valueIR = ir[i];
    }
  }

  if (bestIR >= 33 || bestIR <= 3) {
    BallA = 0;                            //0
  }
  else if (bestIR >= 4 && bestIR <= 14) {
    BallA = 1;                            //1
  }
  else if (bestIR >= 15 && bestIR <= 21) {
    BallA = 2;                            //2
  }
  else if (bestIR >= 24 && bestIR <= 30) {
    BallA = 3;                            //3
  }

  distance = 35;                             //Random Entfernung zum Ball festgelegt !!!!!!!!!!!!!!!!!!!!!!distance > x/y-Smooth
  if (valueIR < 500) {
    distance = 25;
    if (valueIR < 400) {
      distance = 20;
    }
  }

  ballAngle = bestIR * 10;
  if (ballAngle == 0) {
    ballAngle = 1;
  }
  if (ballAngle == 180) {
    ballAngle = 179;
  }

  xSmooth = 20;
  ySmooth = 20;

  ballX = cos(ballAngle * PI / 180) * distance;
  ballY = sin(ballAngle * PI / 180) * distance;

  if (ballAngle > 0 && ballAngle < 180) {
    driveAngle = atan2(ballY - ySmooth - 3.5 , ballX);
    if (ballAngle >= 60 && ballAngle <= 120) {
      driveAngle = 0.5 * PI;
      v = 1.3;
      if (abs(pixyx) > pixyAbweichung && lichtschranke) {
        pixyAngle = 30;
        if (pixyx > 0) {
          pixyAngle = -30;
        }
      }
    }
  }
  else if (ballAngle > 180 && ballAngle <= 270) {
    if (abs(ballX) > abs(xSmooth)) {
      driveAngle = 1.5 * PI - atan2(abs(ballX) - abs(xSmooth) , abs(ballY));
    }
    else if (abs(ballX) < abs(xSmooth)) {
      driveAngle = 1.5 * PI  + atan2(abs(xSmooth) - abs(ballX) , abs(ballY)) ;
    }
  }
  else if (ballAngle > 270) {
    if (ballX < xSmooth) {
      driveAngle = 1.5 * PI - atan2(xSmooth - ballX , abs(ballY));
    }
    else if (ballX > xSmooth) {
      driveAngle = 1.5 * PI  + atan2(ballX - xSmooth, abs(ballY));
    }
  }
  driveAngle = driveAngle + pixyAngle;
  x = cos(driveAngle) * irspeed * v;
  y = sin(driveAngle) * irspeed * v;

  if (valueIR > 900) {
    valueIR = 899;
    torwart = true;
  }
}

////////////////////////////////////////////////////////////////////////////////////////////////////////////////////////////

void XY() {
  mL = (x / 3) + (y / 1.7);
  mR = (x / 3) - (y / 1.7);
  mH = (2 * x) / 3;
}

////////////////////////////////////////////////////////////////////////////////

void Kalibrieren (int k = 0) {
  beep();
  while (k == 0) {
    if (digitalRead(24) == LOW) {
      minx = 10000;
      miny = 10000;
      maxx = -10000;
      maxy = -10000;
      int v = 7;
      mL = v;
      mR = v;
      mH = -v;
      motorenAnsteuern();

      for (int a = 0; a <= 300; a++) {
        imu.readMag();
        if (imu.mx > maxx) {
          maxx = imu.mx;
        }
        if (imu.mx < minx) {
          minx = imu.mx;
        }
        if (imu.my > maxy) {
          maxy = imu.my;
        }
        if (imu.my < miny) {
          miny = imu.my;
        }
        delay(10);
      }

      EEPROM.put(0, minx);
      EEPROM.put(10, miny);
      EEPROM.put(20, maxx);
      EEPROM.put(30, maxy);
      mL = 0;
      mR = 0;
      mH = 0;
      motorenAnsteuern();
    }
    if (digitalRead(25) == LOW) {
      EEPROM.get(0, minx);
      EEPROM.get(10, miny);
      EEPROM.get(20, maxx);
      EEPROM.get(30, maxy);
      imu.readMag();
      xmittel = (maxx + minx) / 2;
      ymittel = (maxy + miny) / 2;
      add1 = atan2((imu.my - ymittel), (imu.mx - xmittel)) * 180. / M_PI;
      k = 1;
    }
  }
}
///////////////////////////////////////////////////////////////////////////////////////////////////////////////////////////////////////////////////////////////////77
void motorenAnsteuern() {            // Die Leistungsstufe wird an die Motoren ausgegeben
  if (valueIR < 900) {
    mL = mL - r;
    mR = mR - r;
    mH = -mH - r;
  }
  else {
    mL = -r;
    mR = -r;
    mH = -r;
  }

  if (mR > 255) mR = 255;
  if (mL > 255) mL = 255;
  if (mH > 255) mH = 255;

  if (mR < -255) mR = -255;
  if (mL < -255) mL = -255;
  if (mH < -255) mH = -255;

  //////////////RECHTS///////////////////////
  if (mR >= 0) {
    digitalWrite(mRInA, HIGH);
    digitalWrite(mRInB, LOW);
    analogWrite(mRPWM, mR);
  }
  else {
    digitalWrite(mRInA, LOW);
    digitalWrite(mRInB, HIGH);
    analogWrite(mRPWM, -mR);
  }
  /////////////LINKS/////////////////////////
  if (mL >= 0) {
    digitalWrite(mLInA, HIGH);
    digitalWrite(mLInB, LOW);
    analogWrite(mLPWM, mL);
  }
  else {
    digitalWrite(mLInA, LOW);
    digitalWrite(mLInB, HIGH);
    analogWrite(mLPWM, -mL);
  }
  /////////////HINTEN////////////////////////
  if (mH >= 0) {
    digitalWrite(mHInA, HIGH);
    digitalWrite(mHInB, LOW);
    analogWrite(mHPWM, mH);
  }
  else {
    digitalWrite(mHInA, LOW);
    digitalWrite(mHInB, HIGH);
    analogWrite(mHPWM, -mH);
  }
}

void beep () {
  mL = mR = mH = 0;
  r = 2;
  motorenAnsteuern();
  delay(30);
  mL = mR = mH = 0;
  r = 0;
  motorenAnsteuern();
}


void setup() {
  // put your setup code here, to run once:
  Serial.begin(115200);
  Serial2.begin(115200);
  Serial3.begin(115200);
  delay(500);
  Serial3.print("$$$");
  delay(500);
  Serial3.println("C,000666D2CCC2");

  pixy.init();
  imu.settings.device.commInterface = IMU_MODE_I2C;
  imu.settings.device.mAddress = LSM9DS1_M;
  imu.settings.device.agAddress = LSM9DS1_AG;

  if (!imu.begin())
  {
    Serial.println("Failed to communicate with LSM9DS1.");
    Serial.println("Double-check wiring.");
    Serial.println("Default settings in this sketch will " \
                   "work for an out of the box LSM9DS1 " \
                   "Breakout, but may need to be modified " \
                   "if the board jumpers are.");
    while (1) {
    }

  }

  pinMode(2, OUTPUT);   //MOTOR R
  pinMode(37, OUTPUT);
  pinMode(38, OUTPUT);  //MOTOR Schuss
  pinMode(11, OUTPUT);
  pinMode(1, OUTPUT);  //MOTOR H
  pinMode(39, OUTPUT);
  pinMode(35, OUTPUT);  //MOTOR L
  pinMode(36, OUTPUT);
  pinMode(34, OUTPUT);  //Multiplexer S3
  pinMode(33, OUTPUT);  //Multiplexer S2
  pinMode(32, OUTPUT);  //Multiplexer S1
  pinMode(31, OUTPUT);  //Multiplexer S0

  pinMode(24, INPUT);   //Knopf 1
  pinMode(25, INPUT);   //Knopf 2
  pinMode(26, INPUT);   //Knopf 3
  pinMode(27, INPUT);   //Knopf 4
  pinMode(28, INPUT);   //Knopf 5


  pinMode(A6, INPUT);    //IR0
  pinMode(A7, INPUT);    //IR1
  pinMode(A8, INPUT);    //IR2
  pinMode(A9, INPUT);    //IR3
  pinMode(A11, INPUT);   //IR4
  pinMode(A10, INPUT);   //IR5
  pinMode(A21, INPUT);   //IR22
  pinMode(A22, INPUT);   //IR23
  pinMode(A2, INPUT);    //IR24
  pinMode(A3, INPUT);    //IR25
  pinMode(A4, INPUT);    //IR26
  pinMode(A5, INPUT);    //IR27


  pinMode(15, INPUT);   //Multiplexer Sig
  pinMode(A0, INPUT);   //Lichtschranke

  Wire2.begin();

  valueIR = 899;
  Kalibrieren();
  beep();
  j = 0;
  d = 4;
}

bool run;
void loop() {
  // put your main code here, to run repeatedl
  Lichtschranke();
  Pixyy();
  torwart = false;
  if (Serial2.available()) {
    z = Serial2.read();
  }
  if (Serial3.available()) {
    p = Serial3.read();
  }
  US();
  IR();
  IRAlgorithm();
  if (p == 5) {
    torwart = true;
  }
  if (torwart) {
    Torwart();
  }
  if (z < 12) {
    x = cos(z * PI * 6) * 100;
    y = sin(z * PI * 6) * 100;
    j = 0;
    BallRest = true;
  }
  else if (z >= 30) {
    if (j == 0 && (z - 30) == BallA) {
      d = BallA;
      j = 1;
    }
    if (BallA != d) {
      BallRest = false;
    }
    if ((z - 30) == BallA && BallRest) {
      x = 0;
      y = 0;
    }
  }
  XY();
  MagDeg();
  CompassRotate();
  motorenAnsteuern();
  while (Serial2.available()) {
    Serial2.read();
  }
}

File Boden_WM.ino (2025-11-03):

//for (int i = 0; i < 4; i++) {
//    if (q[i] < schwell) {
//      qCounter++;
//      boden = true;
//      qSum = qSum + i * 90 + 45;
//    }
//  }

int schwell = 3500;
int schwellka = 3300;
int ka[6];
int ki[18];
int q[4];

int kaCounter;
int qCounter;
int kaSum;
int qSum;

int driveDirec;

int z;
int dt = 8500;
int b; 

unsigned long topR, bottomR, right, left, topL, bottomL;

unsigned long FloorTimer;
int FloorCounter;
int k;
////////////

bool boden;

void BodenRead() {
  boden = false;

  ki[0] = analogRead(A10);
  ki[1] = analogRead(A5);
  ki[2] = 10000;
  ki[3] = 10000;
  ki[4] = 10000;
  ki[5] = 10000;
  ki[6] = 10000;
  ki[7] = 10000;
  ki[8] = analogRead(A20);
  ki[9] = analogRead(A15);
  ki[10] = analogRead(A2);
  ki[11] = analogRead(A13);
  ki[12] = analogRead(A21);
  ki[13] = analogRead(A14);
  ki[14] = analogRead(A7);
  ki[15] = analogRead(A18);
  ki[16] = analogRead(A17);
  ki[17] = analogRead(A6);

  ka[0] = analogRead(A22);
  ka[1] = analogRead(A11);
  ka[2] = analogRead(A1);
  ka[3] = analogRead(A3);
  ka[4] = analogRead(A16);
  ka[5] = analogRead(A19);

  q[0] = analogRead(A12);
  q[1] = analogRead(A4);
  q[2] = analogRead(A8);
  q[3] = analogRead(A9);

  analogReadResolution(12);
  
}

void BodenProcess () {
  bool c = false; 
  kaCounter = 0;
  kaSum = 0;
  
  if (millis() > FloorTimer + dt) {
    FloorCounter = 0;
    }
  ////////////////////////////////  
  if (millis() > topR + 1000) {
    topR = 0;
  }
  if (millis() > topL + 1000) {
    topL = 0;
  }
  if (millis() > bottomL + 1000) {
    bottomL = 0;
  }
  if (millis() > bottomR + 1000) {
    bottomR = 0;
  }
  //Äußere Bodensensoren -
  if (ka[0] < schwellka) {
    right = millis();
    c = true;
    b = 0; 
  }
  if (ka[1] < schwellka) {
    topR = millis();
    if (ka[2] < schwellka) {
      c = true;
      b = 1;
      }
  }
  if (ka[2] < schwellka) {
    topL = millis();
  }
  if (ka[3] < schwellka) {
    left = millis();
    c = true;
    b = 2; 
  }
  if (ka[4] < schwellka) {
    bottomL = millis();
    if (ka[5] < schwellka) {
      c = true;
      b = 3;
      }
  }
  if (ka[5] < schwellka) {
    bottomR = millis();
  }
  //--
  //Äußerer Kreis
  for (int i = 0; i < 6; i++) {
    if (ka[i] < schwellka) {
      int a = 0;
      if (right > left && (bottomR || bottomL) != 0 && i < 3) {
        a = 6;
      }
      kaCounter++;
      boden = true;
      kaSum = kaSum + (i + a) * 60;
    }
  }

  //Innerer Kreis
  if (!boden) {
    for (int i = 0; i < 18; i++) {
      if (ki[i] < schwell) {
        boden = true;
      }
    }
  }
  //QUADRAT
  for (int i = 0; i < 4; i++) {
    if (q[i] < schwell) {
      //int a = 0;
      //if (bottomR != 0 && i == 1) {
        //a = 6;
      //}
      //qCounter++;
      boden = true;
      //qSum = qSum + (i + a) * 90 + 45;
    }
  }
/////////////////////////////////////////////////////////////////
  if (!c && k == 1) {
    k = 0;
    FloorCounter++;
  }
  else if (c) {
    k = 1;
    FloorTimer = millis();
  }
////////////////////////////////////////////////////////////////
}
  
//
void DireC() {
  if (kaCounter >= 2) {
    driveDirec = kaSum / kaCounter;
  }
  else if (kaCounter == 1) {
    if (ka[0] < schwellka && bottomR == 0 && topR == 0) {
      driveDirec = 0;
    }
    else if (ka[3] < schwellka && bottomR == 0 && topR == 0) {
      driveDirec = 180;
    }
    else {
      driveDirec = driveDirec;
    }
  }
}


void setup() {
  // put your setup code here, to run once:
  Serial.begin(115200);
  Serial1.begin(115200);
  pinMode(A1, INPUT);
  pinMode(A2, INPUT);
  pinMode(A3, INPUT);
  pinMode(A4, INPUT);
  pinMode(A5, INPUT);
  pinMode(A6, INPUT);
  pinMode(A7, INPUT);
  pinMode(A8, INPUT);
  pinMode(A9, INPUT);
  pinMode(A10, INPUT);
  pinMode(A11, INPUT);
  pinMode(A12, INPUT);
  pinMode(A13, INPUT);
  pinMode(A14, INPUT);
  pinMode(A15, INPUT);
  pinMode(A16, INPUT);
  pinMode(A17, INPUT);
  pinMode(A18, INPUT);
  pinMode(A19, INPUT);
  pinMode(A20, INPUT);
  pinMode(A21, INPUT);
  pinMode(A22, INPUT);

  left = right = bottomR = topR = topL = bottomL = 0;
  FloorTimer = 0;
  FloorCounter = 0;
  k = 0;
}

void loop() {
  // put your main code here, to run repeatedly:
  if (FloorCounter >= 8) {
    FloorCounter = 0;
    }
  BodenRead();
  BodenProcess();
  //Serial.print("BODEN:"); Serial.print(boden); Serial.print("    k:"); Serial.print(k); Serial.print("   FLOORCOUNTER:"); Serial.print(FloorCounter); Serial.print("  b:"); Serial.println(b); 
  DireC();
  z = driveDirec - 180;
  if (z < 0) {
    z = z + 360;
  }
  z = z / 30;
  if (!boden) {                                                    //Jessi ist nice ... mega nice 
    if (FloorCounter >= 5 && FloorCounter <= 7) {
      z = 30 + b;
      } 
    else {
      z = 20;
      }
  }
  Serial1.write(z);
  //Serial.print("BODEN:"); Serial.print(boden); Serial.print("           kaCounter:"); Serial.print(kaCounter); Serial.print("               z:"); Serial.println(z*30);
}
